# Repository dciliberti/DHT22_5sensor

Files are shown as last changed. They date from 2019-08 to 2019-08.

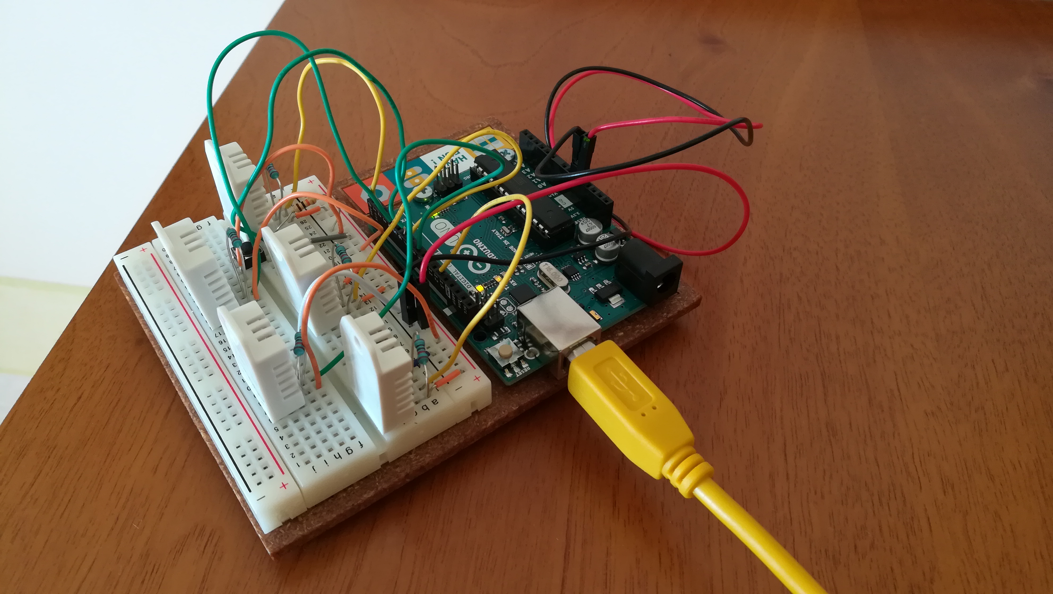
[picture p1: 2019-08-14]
docs/cover.jpg

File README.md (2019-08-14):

# Test DHT22 Sensors with Arduino and MATLAB
This project shows how to use MATLAB and Arduino to acquire and fix data from a bundle of DHT22 sensors, live plot, and export the results. This project has also been uploaded on [Arduino Project Hub](https://create.arduino.cc/projecthub/dancili/test-dht22-sensors-with-arduino-and-matlab-74e81d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).

## More details
Have you bought a bundle of temperature and humidity sensors and you have to pick up one for your project? Aren't you sure of their readings? Do you need to correct the acquired data? This project may help you!

I have been inspired by a [MATLAB tutorial](https://www.mathworks.com/videos/plotting-live-data-of-a-temperature-sensor-using-arduino-and-matlab-121317.html) about live plotting the temperature data acquired with Arduino. I also have a package with 5 DHT22 sensors, which I wanted to test together, to see if they read the same values and they are within the tolerance limits established by the manufacturer.

The codes here uploaded should work flawlessly, provided that you have the required MATLAB packages and you have assigned the right serial port in the MATLAB script. Please, see the comments in the [code](DHT22_5sensor.m).

Since the MATLAB code works with a loop, you may want to disable the Arduino reset when communicating with the serial port. Add a 10uf capacitor between GND and RESET, [as explained here](https://playground.arduino.cc/Main/DisablingAutoResetOnSerialConnection).

The data correction, useful to align the readings of the 5 sensors, was made by checking the live values with a laboratory instrument. In my case, the sensor number 5 was the only one that correctly read both humidity and temperature in several conditions. The other sensors measured different humidity values, but the same temperature. Thus, I have used data acquired in two tests from sensor number 5 to correct the humidity readings of the other sensors. In the code here uploaded this section is commented and MATLAB will plot and export data as they are acquired from the sensors. No user action is necessary. Please see the comments in the code and, if desired, [edit the correction function](humCorr.m) according to your needs.

The DHT22 sensor should have a built-in resistor, but adding another 10 KOhm resistor is not a problem and should not alter the readings.

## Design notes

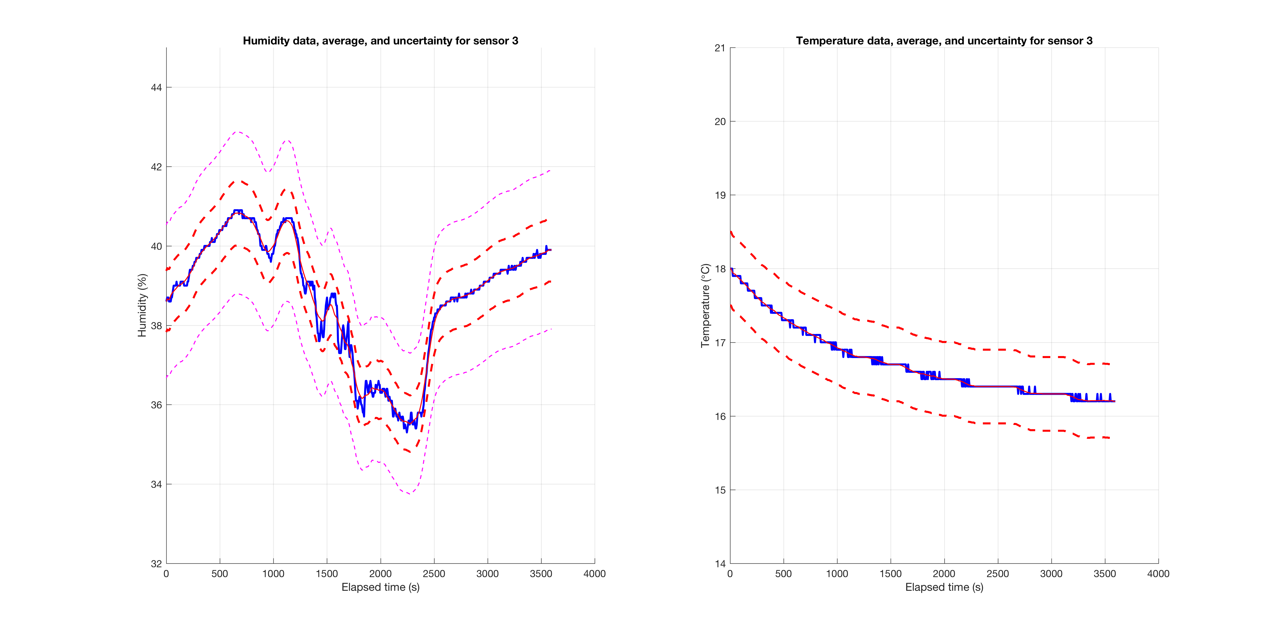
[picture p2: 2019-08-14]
example/sensor3.png

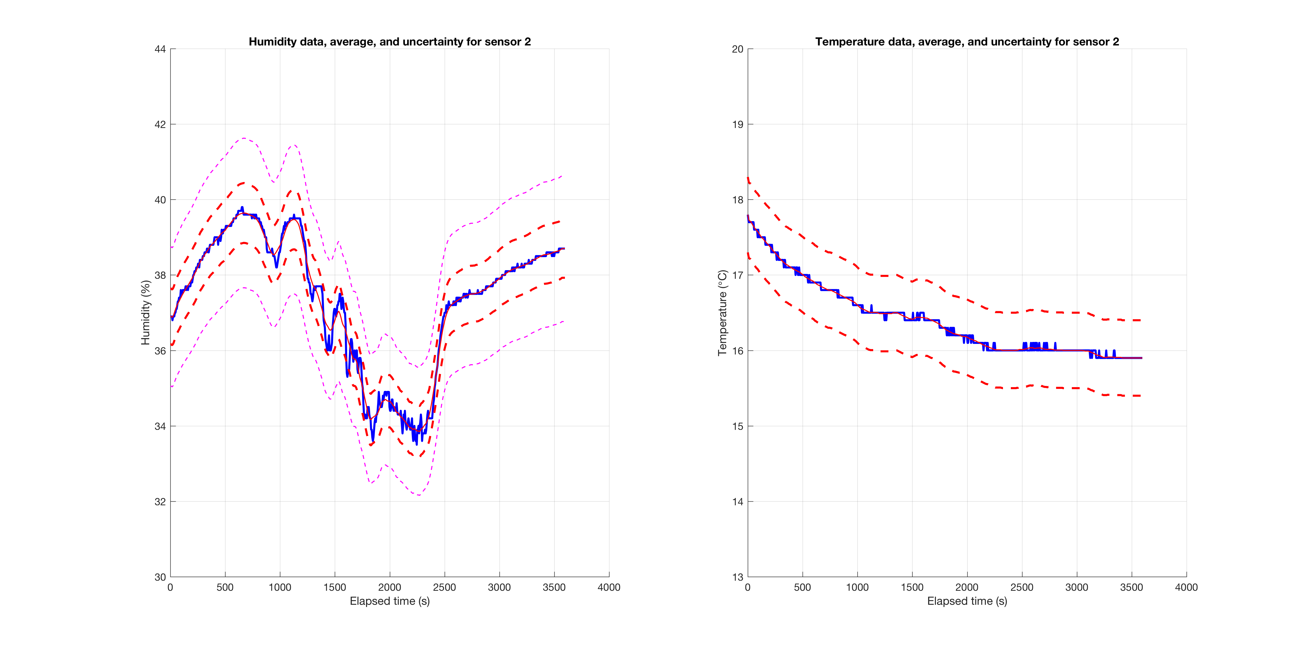
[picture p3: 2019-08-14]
example/sensor2.png

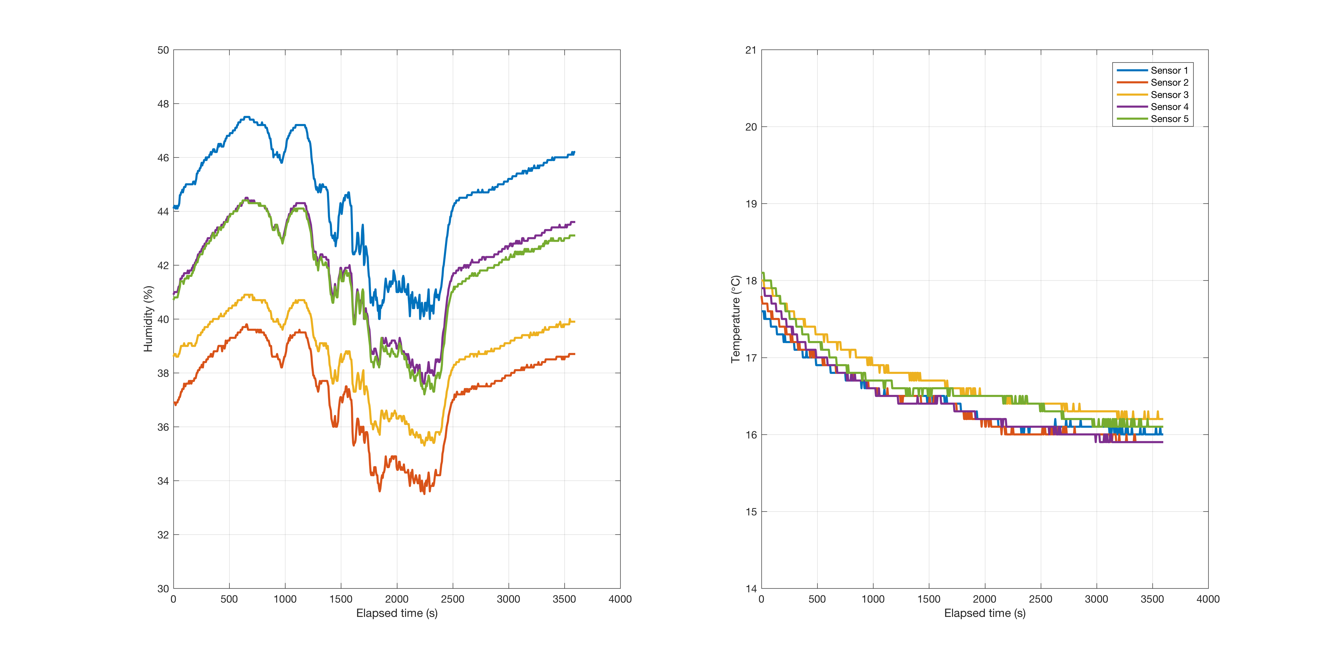
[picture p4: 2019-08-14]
example/DHT22_5sensor.png

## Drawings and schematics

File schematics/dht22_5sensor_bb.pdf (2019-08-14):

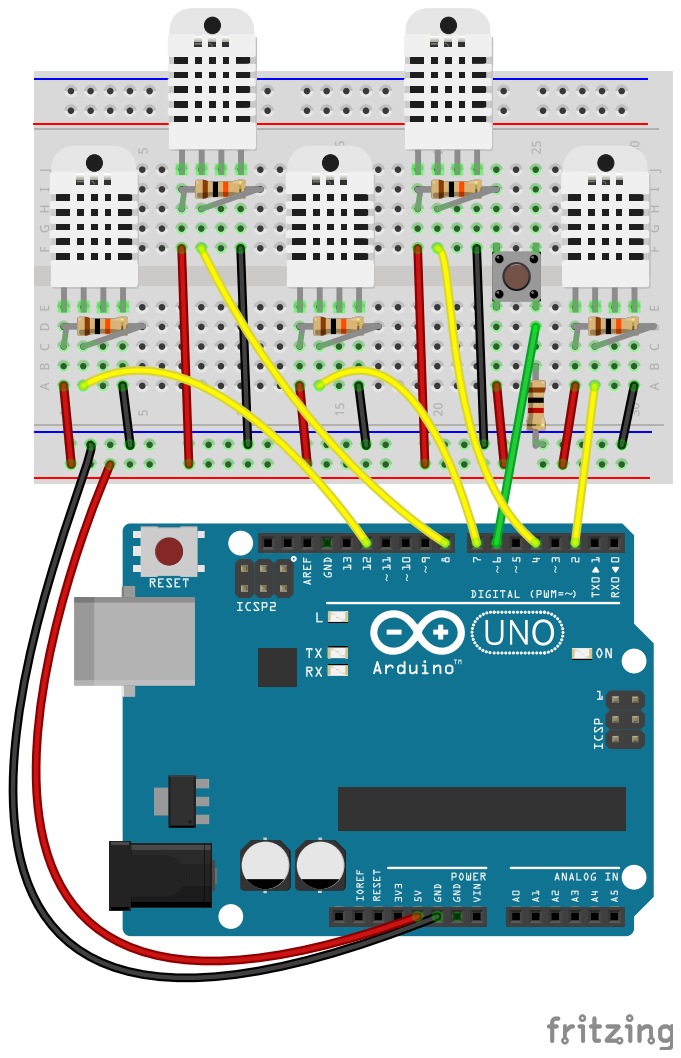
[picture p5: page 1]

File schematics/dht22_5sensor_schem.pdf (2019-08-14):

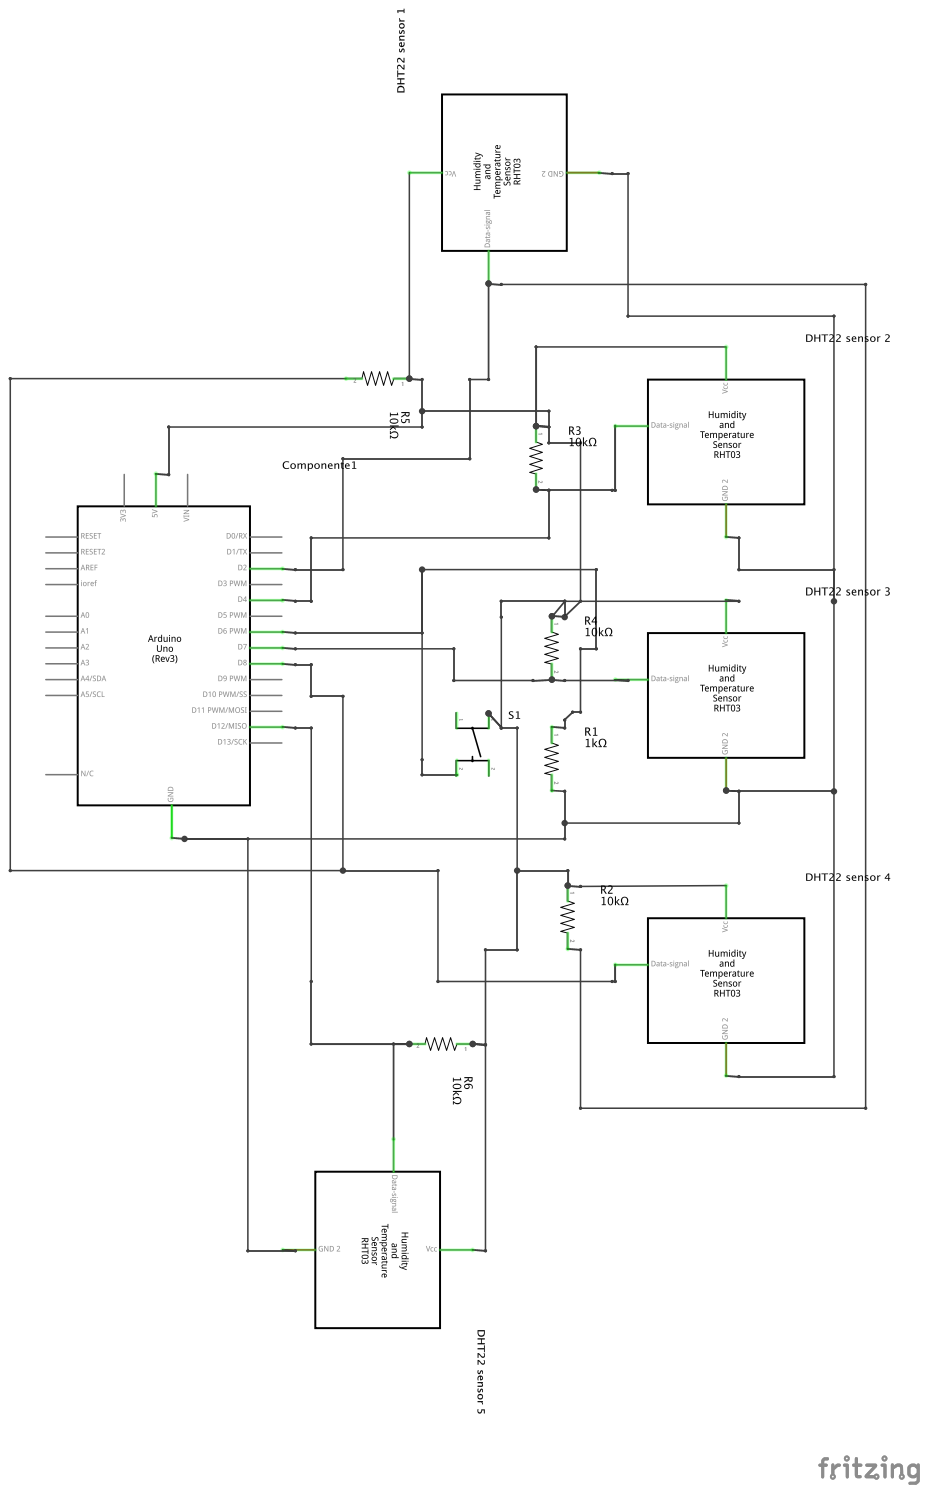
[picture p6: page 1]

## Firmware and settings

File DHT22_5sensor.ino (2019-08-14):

/*
    Arduino sketch to read sensors data and pass them to the computer through the serial port.
    Copyright (C) 2018  Danilo Ciliberti dancili@gmail.com

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
    You should have received a copy of the GNU General Public License
    along with this program.  If not, see <https://www.gnu.org/licenses/>
*/

// Libraries
#include <DHT.h>


// Initialize DHT sensor for normal 16mhz Arduino
DHT dht1(2, DHT22);
DHT dht2(4, DHT22);
DHT dht3(7, DHT22);
DHT dht4(8, DHT22);
DHT dht5(12, DHT22);

int const stopPin = 6;
int stopFlag = 0;


// Variables
float hum;  //Stores humidity value
float temp; //Stores temperature value

void setup()
{
  pinMode(stopPin, INPUT);
  Serial.begin(9600);
  dht1.begin();
  dht2.begin();
  dht3.begin();
  dht4.begin();
  dht5.begin();
}

void loop()
{
    delay(2000);

    // Read humidity from the 5 sensors and display it on a single line
    hum = dht1.readHumidity();
    Serial.print(hum);
    Serial.print(":");
    hum = dht2.readHumidity();
    Serial.print(hum);
    Serial.print(":");
    hum = dht3.readHumidity();
    Serial.print(hum);
    Serial.print(":");
    hum = dht4.readHumidity();
    Serial.print(hum);
    Serial.print(":");
    hum = dht5.readHumidity();
    Serial.print(hum);
    Serial.print(":");

    // Read temperature from the 5 sensors and display it on a single line
    temp = dht1.readTemperature();
    Serial.print(temp);
    Serial.print(":");
    temp = dht2.readTemperature();
    Serial.print(temp);
    Serial.print(":");
    temp = dht3.readTemperature();
    Serial.print(temp);
    Serial.print(":");
    temp = dht4.readTemperature();
    Serial.print(temp);
    Serial.print(":");
    temp = dht5.readTemperature();

    // Check stop condition
    stopFlag = digitalRead(stopPin);
      if (stopFlag == LOW){
        Serial.println(temp);
      }
      else{
        Serial.print(temp);
        Serial.println(":999");
      }
    
}

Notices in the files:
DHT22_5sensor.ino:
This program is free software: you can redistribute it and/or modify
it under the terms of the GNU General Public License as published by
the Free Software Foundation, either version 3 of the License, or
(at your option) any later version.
